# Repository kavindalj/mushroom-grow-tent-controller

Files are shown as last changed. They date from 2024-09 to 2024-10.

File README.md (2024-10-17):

# Mushroom Grow Tent Controller

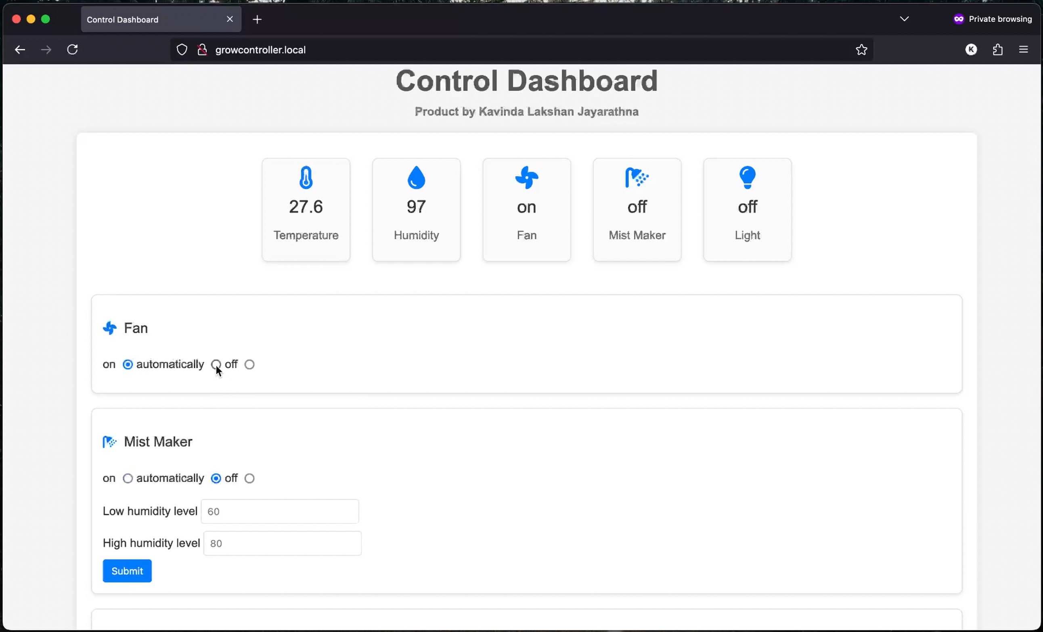
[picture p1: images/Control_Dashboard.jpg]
Control Dashboard
   
   
   For more images, visit the [images folder](./images).

The **Mushroom Grow Tent Controller** is an IoT device designed to automate and control the environment inside a mushroom grow tent. It provides full control of temperature, humidity, and lighting, making it ideal for mushroom cultivation.

This project utilizes an **ESP32 board** along with other components to manage the mist maker, fan, and light. The device operates both in **Access Point mode** and **WiFi mode**, and can be controlled through a web-based UI that is compatible with desktop, tablet, and mobile devices.

## Features

- **Automated Environment Control:**
  - Automatically turns the **mist maker** and **fan** on/off based on user-defined temperature and humidity thresholds.
  - Automatically turns the **light** on/off according to a schedule, synced with NTP servers for accurate timing (requires WiFi mode for NTP synchronization).
  
- **Web-based Control Panel:**
  - Manual control of the **light**, **mist maker**, and **fan** through a user-friendly web UI.
  - Configure the automatic **on/off time** for the light via the web interface.
  - Set the target **temperature** and **humidity** thresholds for the automated control of the mist maker and fan.
  - Real-time display of the **current temperature and humidity**.
  - **Real-time updates** of the **on/off state** for the mist maker, fan, and light across all connected devices.
  - **Configurations are saved**: All user configurations are stored in the **ESP32's flash memory**, so they are **retained even after a power outage**.

- **Modes of Operation:**
  - **Access Point Mode**: The device creates its own WiFi network with the SSID `growcontroller` and password `KLJ_Creations`. The web UI can be accessed at `growcontroller.local`. NTP synchronization for light scheduling is unavailable in this mode.
  - **WiFi Mode**: Connect the device to an existing WiFi network by entering the SSID and password through the UI (`growcontroller.local/wificonfig`). The hostname can be customized when in this mode.

- **Multi-Client Support:**
  - Multiple client devices can connect to the web UI simultaneously. All connected clients receive real-time updates of the system's state.

- **Additional Features:**
  - **NTP Synchronization**: Automatically syncs time with NTP servers for accurate light scheduling (WiFi mode required).
  - **Indicator LEDs**: 
    - One LED indicates when the device is in Access Point mode.
    - Another LED indicates sensor connection failure.
  - **Reset Button**: Press and hold the reset button for 5 seconds to switch to Access Point mode. The Access Point indicator LED will blink, then remain solid once the device enters Access Point mode.

## Technologies Used

- **Programming Languages**: 
  - Arduino
  - HTML
  - CSS
  - JavaScript
  - JSON

- **Libraries & Protocols**:
  - AsyncWebServer
  - WebSockets
  - EEPROM
  - mDNS (Multicast DNS for local network device discovery)
  - NTP (Network Time Protocol) for light scheduling

## Hardware Used

- 1 x **ESP32 board**
- 1 x **DHT11 sensor** (for temperature and humidity measurement)
- 1 x **3-relay module** (for controlling the mist maker, fan, and light)
- 2 x **LEDs** (for mode and sensor failure indication)
- 1 x **Push button** (for resetting to Access Point mode)
- 1 x **230V AC to 5V DC converter** (to power the ESP32)

## Setup Instructions

1. Clone this repository to your local machine:
   ```bash
   git clone https://github.com/kavindalj/mushroom-grow-tent-controller.git
   ```

2. Set up your hardware according to the wiring diagram:

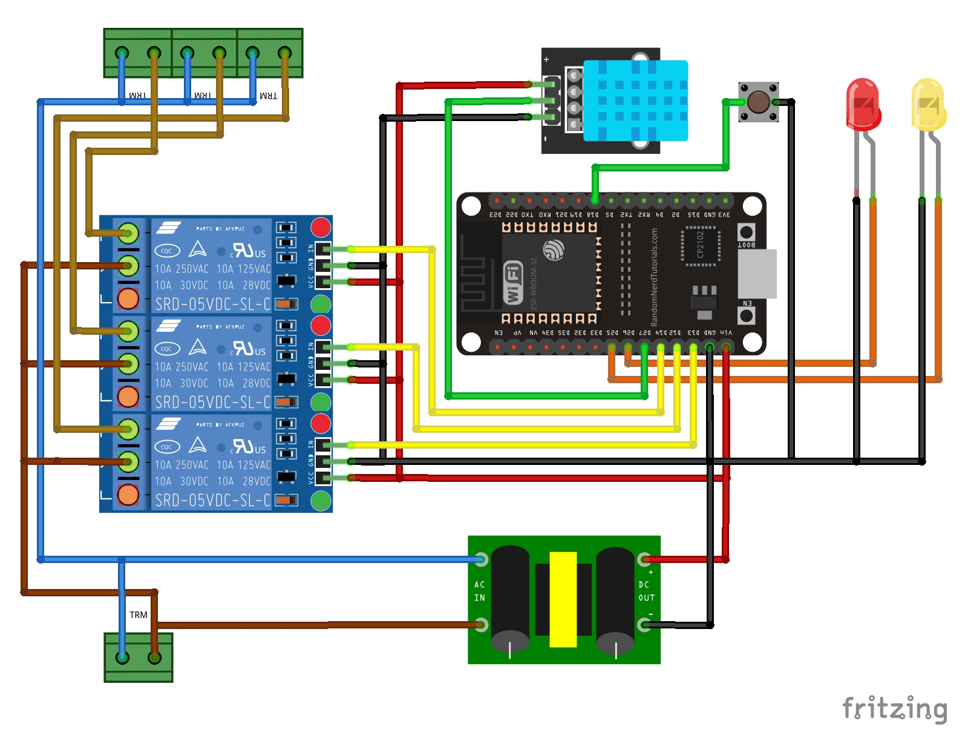
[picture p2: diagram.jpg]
Wiring Diagram
   

3. Flash the ESP32 with the provided Arduino code.

4. Access the web UI:
   - **In Access Point mode**: Connect to the WiFi network `growcontroller` with the password `KLJ_Creations`. Open your browser and go to `growcontroller.local`.
   - **In WiFi mode**: After configuring your WiFi via the UI (`growcontroller.local/wificonfig`), access the device at `hostname.local` (where `hostname` is your custom name for the device).

5. Use the web UI to monitor and control the environment of your grow tent.

## Contributing

Feel free to submit issues or pull requests to contribute to this project. Feedback and improvements are always welcome!

## License

This project is licensed under the MIT License - see the [LICENSE](LICENSE) file for details.

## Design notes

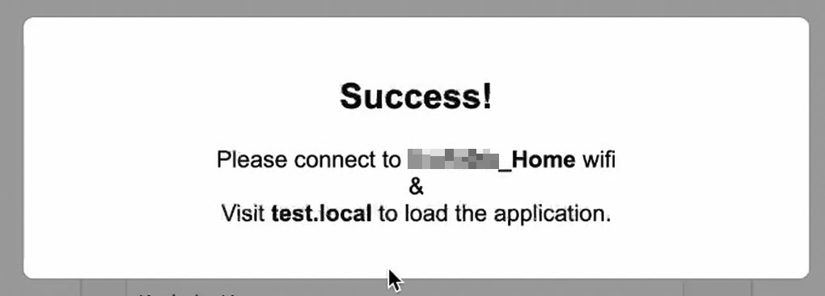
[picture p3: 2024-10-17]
images/message.png

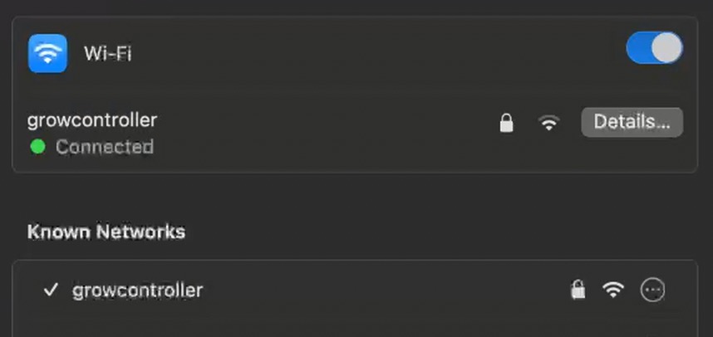
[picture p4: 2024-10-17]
images/access_point.jpg

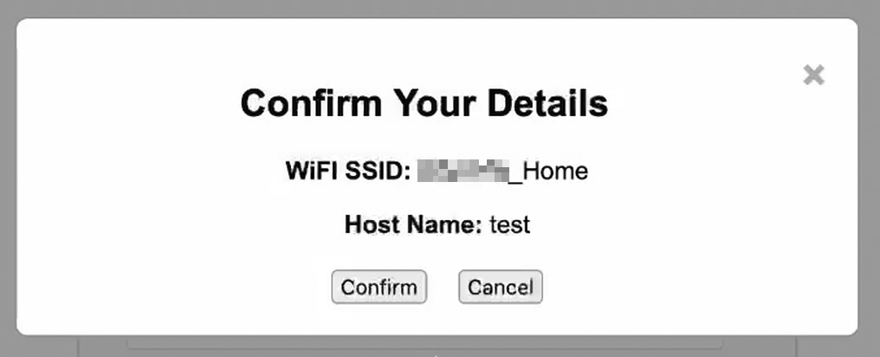
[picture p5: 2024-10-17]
images/confirm_dialog.png

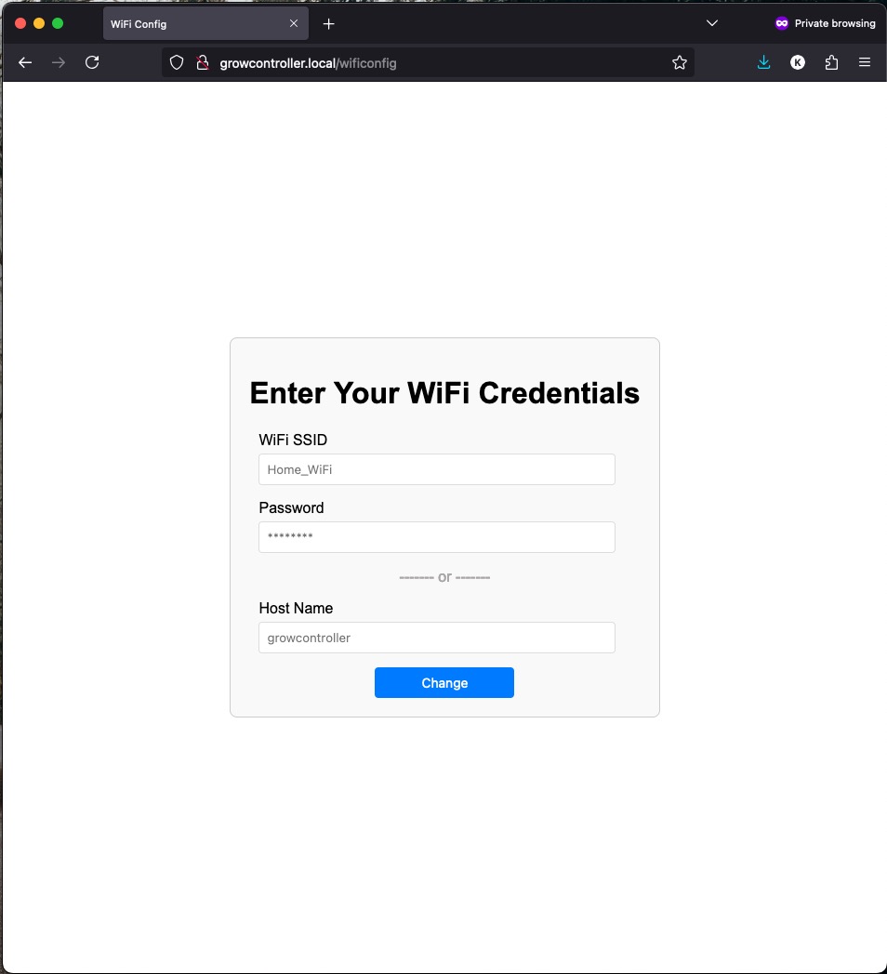
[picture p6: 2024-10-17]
images/wifi.jpg

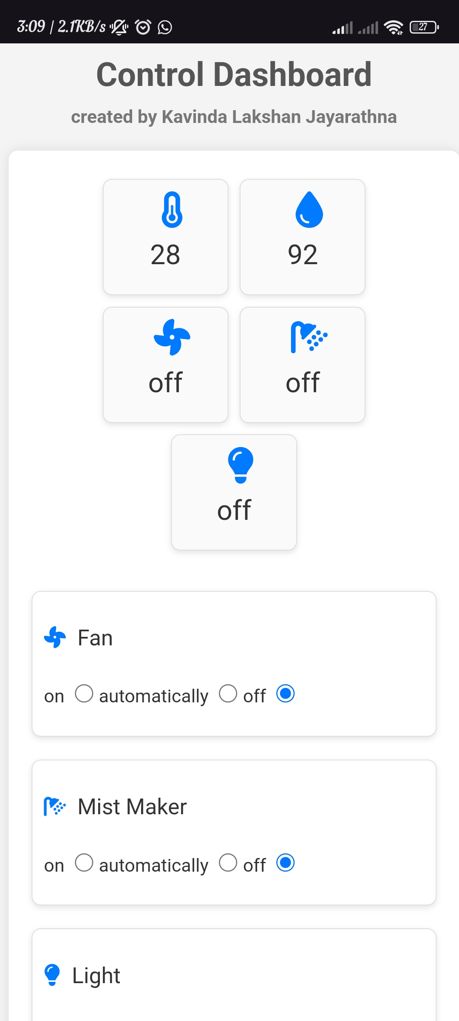
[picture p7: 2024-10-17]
images/Control_Dashboard_mobile.jpg

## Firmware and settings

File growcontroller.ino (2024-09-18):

#include <WiFi.h>
#include <ESPmDNS.h>
#include <ESPAsyncWebServer.h>
#include <WebSocketsServer.h>
#include <ArduinoJson.h>
#include <EEPROM.h>
#include <DHT.h> //DHT and Adafruit Sensor library(https://github.com/adafruit/Adafruit_Sensor)
#include <Ticker.h> //https://github.com/sstaub/Ticker
#include "time.h"

#include "config.h" // import network credentials

#define DHTPIN 27
#define FAN 13
#define MISTMAKER 12
#define LIGHT 14
#define RESETBTN 18

#define SENSORLIGHT 26  // sensor check light
#define APLIGHT 25  // AP Mode light

#define DHTTYPE    DHT11
DHT dht(DHTPIN, DHTTYPE);

const char* ntpServer = "pool.ntp.org";
const long  gmtOffset_sec = 16200;
const int   daylightOffset_sec = 3600;

int resetTimeCounter=0;

// network credentials
// const char* ssid = "SSID";
// const char* password = "PASSWORD";

void send_sensor();
void auto_loop();
void wifi_connect();
bool testWifi(void);
void setupAP(void);
void createWebServer();

Ticker timer;
Ticker looptimer;

char webpage[] PROGMEM = R"=====(

<!DOCTYPE html>
<html>
<head>
  <meta name="viewport" content="width=device-width, initial-scale=1.0">
  <title>Control Dashboard</title>
  <script src="https://kit.fontawesome.com/685df27141.js" crossorigin="anonymous"></script>
  <style>
    body {
      display: flex;
      flex-direction: column;
      align-items: center;
      width: 100%;
      margin-top: 50px;
      font-family: Arial, sans-serif;
      background-color: #f4f4f4;
      color: #333;
    }

    h1 {
      font-size: 2.5em;
      margin-bottom: 10px;
      color: #555;
    }

    h6 {
      font-size: 1em;
      color: #777;
      margin: 0px;
    }

    .mainContainor {
      width: 90%;
      max-width: 1200px;
      display: flex;
      flex-direction: column;
      align-items: center;
      background-color: #fff;
      box-shadow: 0 0 10px rgba(0, 0, 0, 0.1);
      padding: 20px;
      border-radius: 8px;
      margin-top: 20px;
    }

    .statusContainor {
      display: flex;
      flex-wrap: wrap;
      justify-content: center;
      margin-bottom: 30px;
    }

    .statusContainor .componentContainor {
      margin: 15px;
      text-align: center;
      border: 1px solid #ddd;
      border-radius: 8px;
      padding: 10px;
      background-color: #fafafa;
      box-shadow: 0 2px 5px rgba(0, 0, 0, 0.1);
    }

    .statusContainor .componentContainor i {
      font-size: 2em;
      color: #007bff;
      width: 100px;
    }

    .statusContainor .status {
      font-size: 1.5em;
      margin: 10px 0;
    }

    .statusContainor .statusName {
      font-size: 1em;
      color: #666;
    }

    .controlContainor {
      width: 100%;
      display: flex;
      flex-direction: column;
      align-items: stretch;
    }

    .controlContainor .componentContainor {
      display: flex;
      flex-direction: column;
      margin-bottom: 20px;
      background-color: #fff;
      border: 1px solid #ddd;
      border-radius: 8px;
      padding: 15px;
      box-shadow: 0 2px 5px rgba(0, 0, 0, 0.1);
    }

    .controlContainor .componentContainor .label {
      display: flex;
      align-items: center;
      font-size: 1.2em;
      margin-bottom: 10px;
    }

    .controlContainor .componentContainor .label i {
      margin-right: 10px;
      color: #007bff;
    }

    .controlContainor .componentContainor .rightContainor {
      display: flex;
      flex-direction: column;
      align-items: flex-start;
    }

    .controlContainor .componentContainor .statusChange {
      display: flex;
      align-items: center;
      margin-bottom: 15px;
    }

    .controlContainor .componentContainor .statusChange input {
      margin: 0 5px;
    }

    .controlContainor .componentContainor .inputContainor {
      display: flex;
      flex-direction: column;
      align-items: flex-start;
    }

    .controlContainor .componentContainor .inputContainor input {
      margin: 5px 0;
      padding: 8px;
      border: 1px solid #ddd;
      border-radius: 4px;
      width: 200px;
    }

    .controlContainor .componentContainor button {
      padding: 8px 12px;
      border: none;
      border-radius: 4px;
      background-color: #007bff;
      color: #fff;
      cursor: pointer;
      transition: background-color 0.3s;
    }

    .controlContainor .componentContainor button:hover {
      background-color: #0056b3;
    }

    @media (max-width: 480px) {
      body {
        margin-top: 20px;
      }

      h1 {
        font-size: 1.8em;
      }

      .statusContainor {
        flex-direction: row;
      }

      .statusContainor .componentContainor {
        width: 25%;
        margin: 5px;
      }

      .controlContainor .componentContainor {
        padding: 10px;
      }

      .label {
        font-size: 1em;
      }

      .inputContainor input {
        width: 100%;
      }

      .controlContainor .componentContainor button {
        width: 100%;
        margin-top: 10px;
      }
    }
  </style>
</head>

<script>

  var connection = new WebSocket('ws://'+location.hostname+':81/');

  var fanControlStatus = 0;   // store selected state from web
  var mistMakerControlStatus = 0;
  var lightControlStatus = 0;
  
  var temp_data = 0;   // store read data from sensor
  var hum_data = 0;
  var fan_data = 0;   // store pin read state ==> on or off now
  var mistMaker_data = 0;
  var light_data = 0;
  
  var fanSelect_data = 0;   // store read state in EEPROM
  var mistMakerSelect_data = 0;
  var lightSelect_data = 0;

  var lowTempLev = 0;   // store input data
  var highTempLev = 0;
  var lowHumLev = 0;
  var highHumLev = 0;
  var lightOnTime = 0;
  var lightOffTime = 0;

  connection.onmessage = function(event){

    var full_data = event.data;
    console.log(full_data);
    var data = JSON.parse(full_data);

    temp_data = data.temp;
    hum_data = data.hum;
    fan_data = data.fan;
    mistMaker_data = data.mist;
    light_data = data.light;

    fanSelect_data = data.fanSelect;
    mistMakerSelect_data = data.mistMakerSelect;
    lightSelect_data = data.lightSelect;

    lowTempLev = data.lowTemp_level;
    highTempLev = data.highTemp_level;
    lowHumLev = data.lowHum_level;
    highHumLev = data.highHum_level;
    lightOnTime = data.lightOn_time;
    lightOffTime = data.lightOff_time;

    var fanSt;
    var mistSt;
    var lightSt;

    if (fan_data == 0){   // change 1 ==> ON & 0 ==> OFF
      fanSt = "off";
    }
    if (fan_data == 1){
      fanSt = "on";
    }
    if (mistMaker_data == 0){
      mistSt = "off";
    }
    if (mistMaker_data == 1){
      mistSt = "on";
    }
    if (light_data == 0){
      lightSt = "off";
    }
    if (light_data == 1){
      lightSt = "on";
    }

    // for auto check check boxes with saved state in EEPROM
    switch(fanSelect_data) {
      case 0:
        document.getElementById('fanOff').checked = true;
        document.getElementById('fanInput').style.display = 'none';
        break;
      case 1:
        document.getElementById('fanOn').checked = true;
        document.getElementById('fanInput').style.display = 'none';
        break;
      case 2:
        document.getElementById('fanAuto').checked = true;
        document.getElementById('fanInput').style.display = 'flex';
        break;
    }
    switch(mistMakerSelect_data) {
      case 0:
        document.getElementById('mistMakerOff').checked = true;
        document.getElementById('mistMakerInput').style.display = 'none';
        break;
      case 1:
        document.getElementById('mistMakerOn').checked = true;
        document.getElementById('mistMakerInput').style.display = 'none';
        break;
      case 2:
        document.getElementById('mistMakerAuto').checked = true;
        document.getElementById('mistMakerInput').style.display = 'flex';
        break;
    }
    switch(lightSelect_data) {
      case 0:
        document.getElementById('lightOff').checked = true;
        document.getElementById('lightInput').style.display = 'none';
        break;
      case 1:
        document.getElementById('lightOn').checked = true;
        document.getElementById('lightInput').style.display = 'none';
        break;
      case 2:
        document.getElementById('lightAuto').checked = true;
        document.getElementById('lightInput').style.display = 'flex';
        break;
    }

    // update status show in web page
    document.getElementById("temp_value").innerHTML = temp_data;
    document.getElementById("hum_value").innerHTML = hum_data;
    document.getElementById("fan_state").innerHTML = fanSt;
    document.getElementById("mistMaker_state").innerHTML = mistSt;
    document.getElementById("light_state").innerHTML = lightSt;

    // change placeholder text
    document.getElementById('LTL').placeholder = lowTempLev;
    document.getElementById('HTL').placeholder = highTempLev;
    document.getElementById('LHL').placeholder = lowHumLev;
    document.getElementById('HHL').placeholder = highHumLev;
    document.getElementById('LONT').placeholder = lightOnTime;
    document.getElementById('LOFFT').placeholder = lightOffTime;
  }

  // click functions
  function fan_on()
  {
    fanControlStatus = 1; 
    console.log("FAN is ON");
    document.getElementById('fanInput').style.display = 'none';
    send_data();
  }

  function fan_off()
  {
    fanControlStatus = 0;
    console.log("FAN is OFF");
    document.getElementById('fanInput').style.display = 'none';
    send_data();
  }

  function fan_auto()
  {
    fanControlStatus = 2;
    console.log("FAN auto");
    document.getElementById('fanInput').style.display = 'flex';
    send_data();
  }

  function mist_on()
  {
    mistMakerControlStatus = 1; 
    console.log("MIST MAKER is ON");
    document.getElementById('mistMakerInput').style.display = 'none';
    send_data();
  }

  function mist_off()
  {
    mistMakerControlStatus = 0;
    console.log("MIST MAKER is OFF");
    document.getElementById('mistMakerInput').style.display = 'none';
    send_data();
  }

  function mist_auto()
  {
    mistMakerControlStatus = 2;
    console.log("MISTMAKER auto");
    document.getElementById('mistMakerInput').style.display = 'flex';
    send_data();
  }

  function light_on()
  {
    lightControlStatus = 1; 
    console.log("LIGHT is ON");
    document.getElementById('lightInput').style.display = 'none';
    send_data();
  }

  function light_off()
  {
    lightControlStatus = 0;
    console.log("LIGHT is OFF");
    document.getElementById('lightInput').style.display = 'none';
    send_data();
  }

  function light_auto()
  {
    lightControlStatus = 2;
    console.log("LIGHT auto");
    document.getElementById('lightInput').style.display = 'flex';
    send_data();
  }

  // get text user input
  function submit(){
    // get values only input isnt empty
    if(document.getElementById("LTL").value){
      lowTempLev = document.getElementById("LTL").value;
    }
    if(document.getElementById("HTL").value){
      highTempLev = document.getElementById("HTL").value;
    }
    if(document.getElementById("LHL").value){
      lowHumLev = document.getElementById("LHL").value;
    }
    if(document.getElementById("HHL").value){
      highHumLev = document.getElementById("HHL").value;
    }
    if(document.getElementById("LONT").value){
      lightOnTime = document.getElementById("LONT").value;
    }
    if(document.getElementById("LOFFT").value){
      lightOffTime = document.getElementById("LOFFT").value;
    }

    console.log(lowTempLev,highTempLev,lowHumLev,highHumLev,lightOnTime,lightOffTime);
    send_data();
  }

  function send_data()
  {
    var full_data = '{"fanControl" :'+fanControlStatus+',"mistMakerControl":'+mistMakerControlStatus+',"lightControl":'+lightControlStatus+',"ltl":'+lowTempLev+',"htl":'+highTempLev+',"lhl":'+lowHumLev+',"hhl":'+highHumLev+',"lont":'+lightOnTime+',"lofft":'+lightOffTime+'}';
    console.log(full_data);
    connection.send(full_data);
  }
</script>
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
void loop(void)
{
 websockets.loop();
}

// send all data to web
void send_sensor()
{
  // Read humidity
  float h = dht.readHumidity();
  // Read temperature
  float t = dht.readTemperature();

  // Read pins
  bool fan_state = digitalRead(FAN);
  bool mistMaker_state = digitalRead(MISTMAKER);
  bool light_state = digitalRead(LIGHT);

  // Read EEProm for loard selcted state and values
  int fan_selected = EEPROM.read(0);
  int mistMaker_selected = EEPROM.read(1);
  int light_selected = EEPROM.read(2);

  int lowTemp_level = EEPROM.read(3);
  int highTemp_level = EEPROM.read(4);
  int lowHum_level = EEPROM.read(5);
  int highHum_level = EEPROM.read(6);
  int lightOn_time = EEPROM.read(7);
  int lightOff_time = EEPROM.read(8);
  
  if (isnan(h) || isnan(t) ) {
    digitalWrite(SENSORLIGHT,1);
    Serial.println(F("Failed to read from DHT sensor!"));
    return;
  }else{
    digitalWrite(SENSORLIGHT,0);
  }
  if (isnan(fan_state) || isnan(mistMaker_state) || isnan(light_state) ) {
    Serial.println(F("Failed to read from pins!"));
    return;
  }

  // Make data into json format ==> JSON_Data = {"temp":t,"hum":h}
  String JSON_Data = "{\"temp\":";
         JSON_Data += t;
         JSON_Data += ",\"hum\":";
         JSON_Data += h;
         JSON_Data += ",\"fan\":";
         JSON_Data += !fan_state;
         JSON_Data += ",\"mist\":";
         JSON_Data += !mistMaker_state;
         JSON_Data += ",\"light\":";
         JSON_Data += !light_state;
         JSON_Data += ",\"fanSelect\":";
         JSON_Data += fan_selected;
         JSON_Data += ",\"mistMakerSelect\":";
         JSON_Data += mistMaker_selected;
         JSON_Data += ",\"lightSelect\":";
         JSON_Data += light_selected;
         JSON_Data += ",\"lowTemp_level\":";
         JSON_Data += lowTemp_level;
         JSON_Data += ",\"highTemp_level\":";
         JSON_Data += highTemp_level;
         JSON_Data += ",\"lowHum_level\":";
         JSON_Data += lowHum_level;
         JSON_Data += ",\"highHum_level\":";
         JSON_Data += highHum_level;
         JSON_Data += ",\"lightOn_time\":";
         JSON_Data += lightOn_time;
         JSON_Data += ",\"lightOff_time\":";
         JSON_Data += lightOff_time;
         JSON_Data += "}";
   Serial.println(JSON_Data);     
  websockets.broadcastTXT(JSON_Data);
}

// read EEPROM and perform actions related to that data
void auto_loop(){
  // Read EEProm for loard selcted state and values
  int fan_selected = EEPROM.read(0);
  int mistMaker_selected = EEPROM.read(1);
  int light_selected = EEPROM.read(2);

  if (fan_selected != 2){
    digitalWrite(FAN,!fan_selected);
  }else{
    int lowTemp_level = EEPROM.read(3);
    int highTemp_level = EEPROM.read(4);
    float t = dht.readTemperature();
    if ( lowTemp_level >= t ){
      digitalWrite(FAN,1);
    }
    if ( highTemp_level <= t ){
      digitalWrite(FAN,0);
    }
  }

  if (mistMaker_selected != 2){
    digitalWrite(MISTMAKER,!mistMaker_selected);
  }else{
    int lowHum_level = EEPROM.read(5);
    int highHum_level = EEPROM.read(6);
    float h = dht.readHumidity();
    if ( lowHum_level >= h ){
      digitalWrite(MISTMAKER,0);
    }
    if ( highHum_level <= h ){
      digitalWrite(MISTMAKER,1);
    }
  }

  if (light_selected != 2){
    digitalWrite(LIGHT,!light_selected);
  }else{
    struct tm timeinfo;
    if(!getLocalTime(&timeinfo)){
      Serial.println("Failed to obtain time");
      return;
    }

    int lightOn_time = EEPROM.read(7);
    int lightOff_time = EEPROM.read(8);

    Serial.println(&timeinfo, "%A, %B %d %Y %H:%M:%S");
    int currentHour = timeinfo.tm_hour;
    if (lightOn_time <= currentHour && lightOff_time > currentHour){
      digitalWrite(LIGHT,0);
    }else{
      digitalWrite(LIGHT,1);
    }
  }

  //reset button function
  if (digitalRead(RESETBTN)==LOW){
    ++resetTimeCounter;
  }else{
    resetTimeCounter=0;
  }
  Serial.println(resetTimeCounter);
  if(resetTimeCounter==5){
    // indicate reset
    digitalWrite(APLIGHT,1);
    delay(100);
    digitalWrite(APLIGHT,0);
    delay(100);
    digitalWrite(APLIGHT,1);
    delay(100);
    digitalWrite(APLIGHT,0);
    delay(100);
    digitalWrite(APLIGHT,1);
    delay(500);
    digitalWrite(APLIGHT,0);

    Serial.println("Disconnecting previously connected WiFi");
    WiFi.disconnect();
    Serial.println("Turning the HotSpot On");
    setupAP(); // Setup HotSpot
    // Print ESP soft IP Address
    Serial.println(WiFi.softAPIP());

    // Initialize mDNS
    if (!MDNS.begin("growcontroller")) { // hostname on AP mode
      Serial.println("Error starting mDNS");
      return;
    }
    Serial.println("mDNS started");
  }

}

void wifi_connect(){

  Serial.println("Disconnecting previously connected WiFi");
  WiFi.disconnect();

  // Read eeprom for ssid, password and host name
  Serial.println("Reading EEPROM wifi data");

  String esid;
  for (int i = 10; i < 42; ++i)
  {
    esid += char(EEPROM.read(i));
  }
  Serial.println();
  Serial.print("SSID: ");
  Serial.println(esid);

  String epass = "";
  for (int i = 42; i < 106; ++i)
  {
    epass += char(EEPROM.read(i));
  }
  Serial.print("PASS: ");
  Serial.println(epass);
  
  String ehost = "";
  for (int i = 106; i < 138; ++i)
  {
    ehost += char(EEPROM.read(i));
  }
  Serial.print("HOST: ");
  Serial.println(ehost);

  Serial.println("Reading EEPROM pass");

  //connect to wifi
  WiFi.begin(esid.c_str(), epass.c_str());

  //if wifi didn't connect open AP
  if (testWifi())
  {
    Serial.println("Succesfully Connected!!!");
    digitalWrite(APLIGHT,0);
    // Print ESP Local IP Address
    Serial.println(WiFi.localIP());

    configTime(gmtOffset_sec, daylightOffset_sec, ntpServer);

    // Initialize mDNS
    if (!MDNS.begin(ehost.c_str())) { // hostname
      Serial.println("Error starting mDNS");
      return;
    }
    Serial.println("mDNS started");
    return;
  }
  else
  {
    Serial.println("Turning the HotSpot On");
    setupAP(); // Setup HotSpot
    // Print ESP soft IP Address
    Serial.println(WiFi.softAPIP());

    // Initialize mDNS
    if (!MDNS.begin("growcontroller")) { // hostname on AP mode
      Serial.println("Error starting mDNS");
      return;
    }
    Serial.println("mDNS started");
  }
}

bool testWifi(void)
{
  int c = 0;
  Serial.println("Waiting for Wifi to connect");
  while ( c < 20 ) {
    if (WiFi.status() == WL_CONNECTED)
    {
      return true;
    }
    delay(500);
    Serial.print("*");
    c++;
  }
  Serial.println("");
  Serial.println("Connect timed out, opening AP");
  return false;
}

void setupAP(void)
{
  WiFi.mode(WIFI_STA);
  WiFi.disconnect();
  delay(100);

  // int n = WiFi.scanNetworks();
  // Serial.println("scan done");
  // if (n == 0)
  //   Serial.println("no networks found");
  // else
  // {
  //   Serial.print(n);
  //   Serial.println(" networks found");
  //   for (int i = 0; i < n; ++i)
  //   {
  //     // Print SSID and RSSI for each network found
  //     Serial.print(i + 1);
  //     Serial.print(": ");
  //     Serial.print(WiFi.SSID(i));
  //     Serial.print(" (");
  //     Serial.print(WiFi.RSSI(i));
  //     Serial.print(")");
  //     delay(10);
  //   }
  // }
  // delay(100);

  WiFi.softAP("growcontroller", "KLJ_Creations");
  digitalWrite(APLIGHT,1);
  Serial.println("opensoftAP");
}

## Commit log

2024-08-06 automate fan & mist maker
2024-08-17 make simple on off timer
2024-08-25 add sensor check and AP Mode lights
2024-08-25 make diagram
    [diagram.fzz]
2024-08-27 changed code according to relays
2024-09-18 add wifi reset button
2024-09-30 add AC wiring and reset button wiring
    [diagram.fzz]
